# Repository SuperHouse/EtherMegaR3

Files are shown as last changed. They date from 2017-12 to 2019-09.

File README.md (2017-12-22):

EtherMega R3
============
Portions copyright 2011-2013 Freetronics Pty Ltd www.freetronics.com.au  
Portions copyright 2017 SuperHouse Automation Pty Ltd www.superhouse.tv  

The EtherMega R3 is a 100% Arduino-compatible board based on the existing
Mega2560, but with improvements and updates for features and ease of
use. It also includes on-board Ethernet with PoE (Power-over-Ethernet)
support.

Features:

 * High-efficiency switchmode power supply (input voltage 7-28Vdc)
 * Micro-USB Connector
 * microSD card slot
 * 10/100 Ethernet using the Wiznet W5100 chip
 * Overlay guide where you need it (both top and bottom)
 * D13 pin works for everything

You can learn more at:

  https://www.superhouse.tv/ethermega

INSTALLATION
------------
The design is saved as an EAGLE project. EAGLE PCB design software is
available from www.cadsoftusa.com free for non-commercial use. To use
this project download it and place the directory containing these files
into the "eagle" directory on your computer. Then open EAGLE and
navigate to Projects -> eagle -> EtherMegaR3.

DISTRIBUTION
------------
The specific terms of distribution of this project are governed by the
license referenced below.

LICENSE
-------
This work is licensed under the
Creative Commons Attribution-Share Alike License.  
To view a copy of this license, visit

  http://creativecommons.org/licenses/by-sa/3.0/  
  http://creativecommons.org/licenses/by-sa/3.0/legalcode

or send a letter to

  Creative Commons  
  171 Second Street, Suite 300  
  San Francisco  
  California, 94105  
  USA

The "license" folder within this repository also contains copies of the
licences referenced above.

CREDITS
-------
The EtherMega was designed by Marc Alexander (marc@freetronics.com) and
Jonathan Oxer (jon@freetronics.com) based on previous work by the Arduino
team (www.arduino.cc/playground/Main/People) which includes:

 * Massimo Banzi
 * David Cuartielles
 * Tom Igoe
 * Gianluca Martino
 * David A. Mellis

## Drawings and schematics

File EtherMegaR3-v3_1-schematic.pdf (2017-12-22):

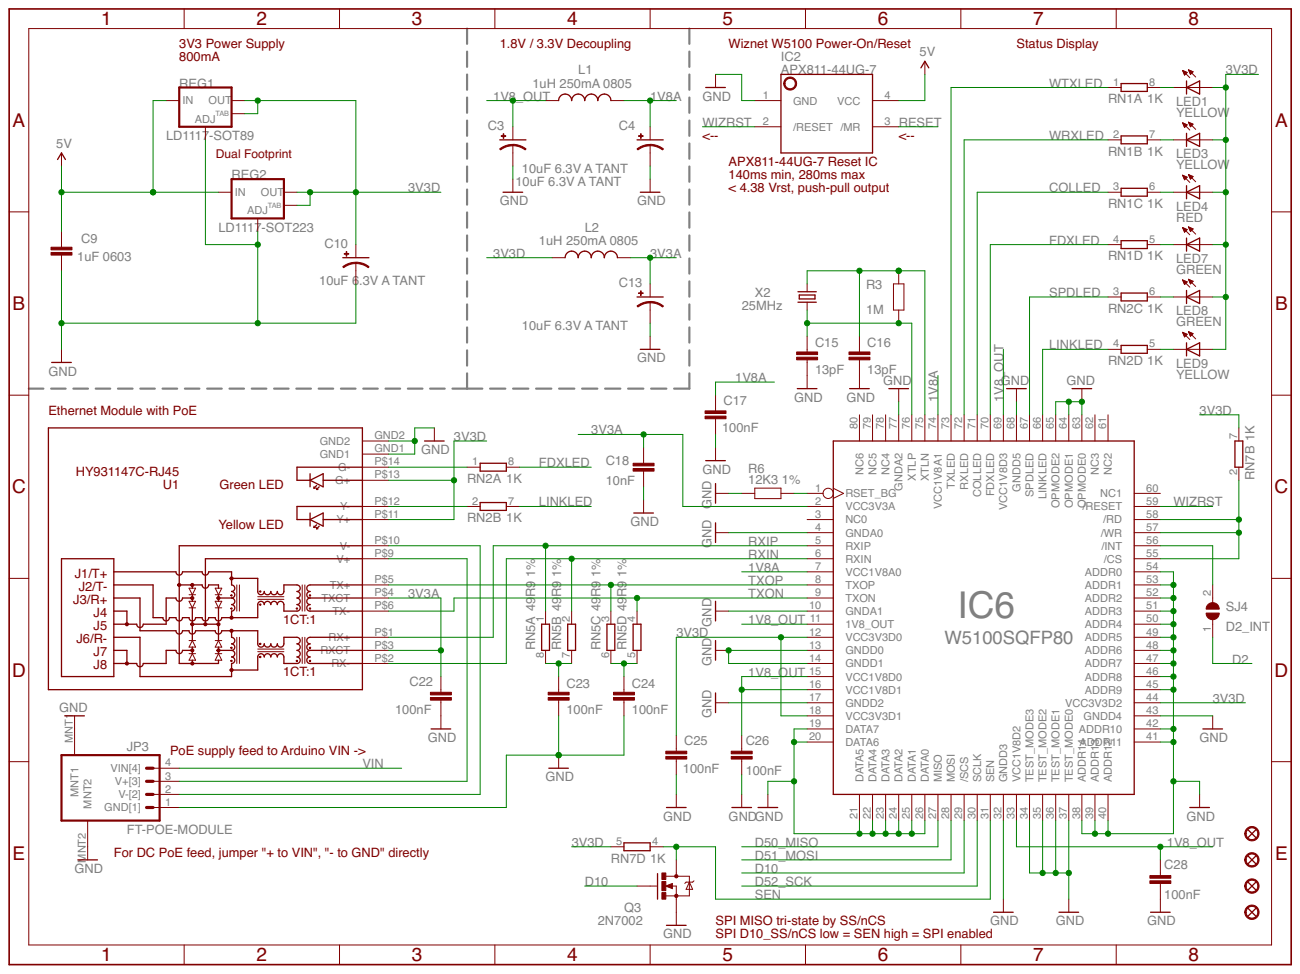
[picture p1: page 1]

Wiznet W5100 Power-On/Reset

Ethernet Module with PoE

GND GND GND GND GND

RXIP | | 56
RXIN | | 55

PoE supply feed to Arduino VIN ->

FT-POE-MODULE
For DC PoE feed, jumper "+ to VIN", "- to GND" directly

SPI MISO tri-state by SS/nCS
SPI D10_SS/nCS low = SEN high = SPI enabled

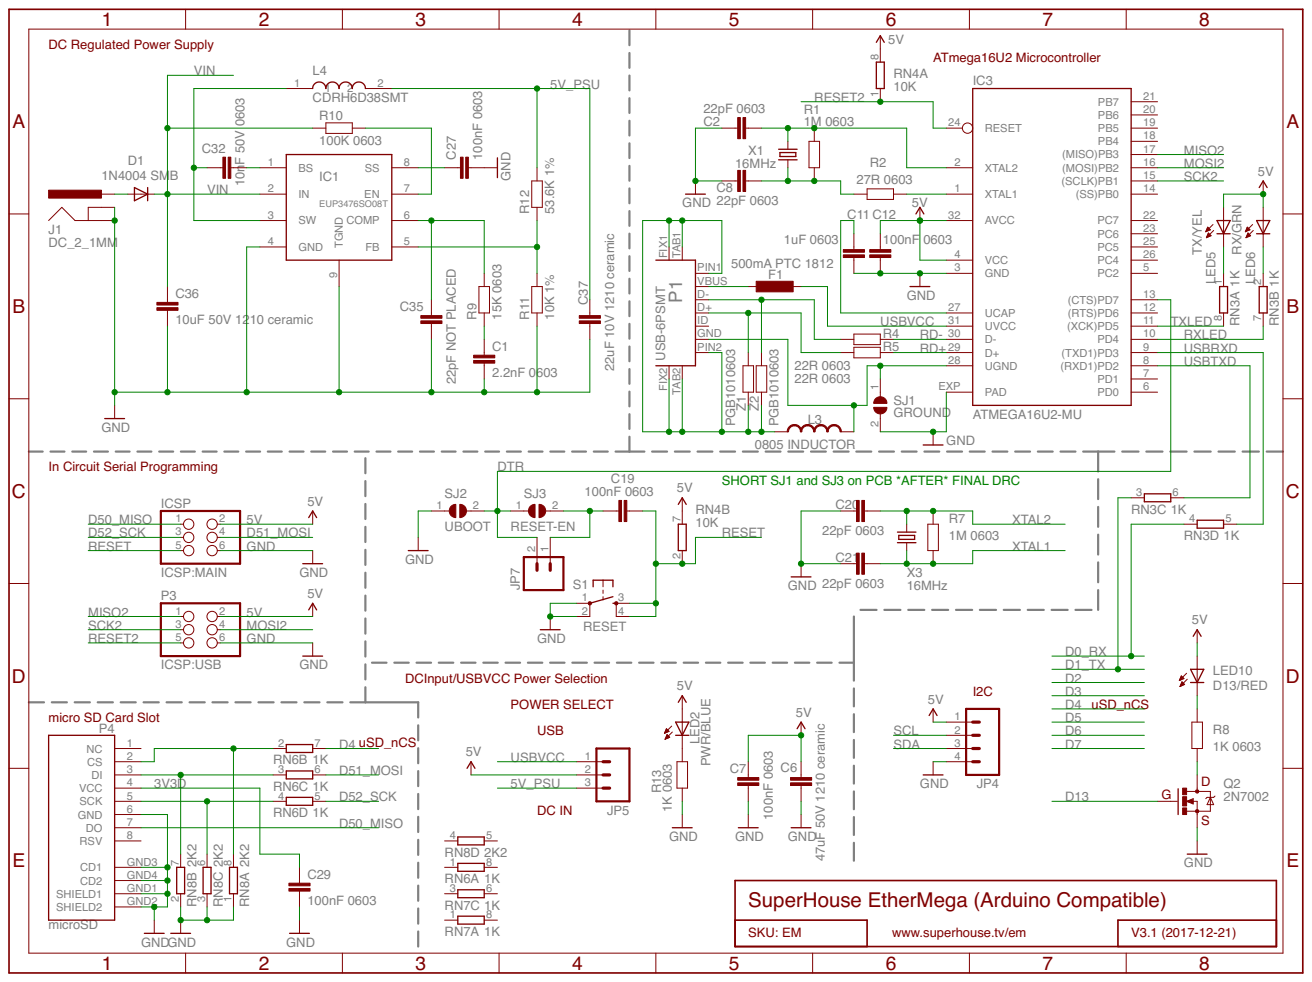
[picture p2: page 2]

DC Regulated Power Supply

10 PD0 8 | USBTXD

R5 | | 9 | USBRXD

EXP

In Circuit Serial Programming

SHORT SJ1 and SJ3 on PCB *AFTER* FINAL DRC

DCInput/USBVCC Power Selection

micro SD Card Slot

4 SCK 3V3D
6 VCC

SuperHouse EtherMega (Arduino Compatible)

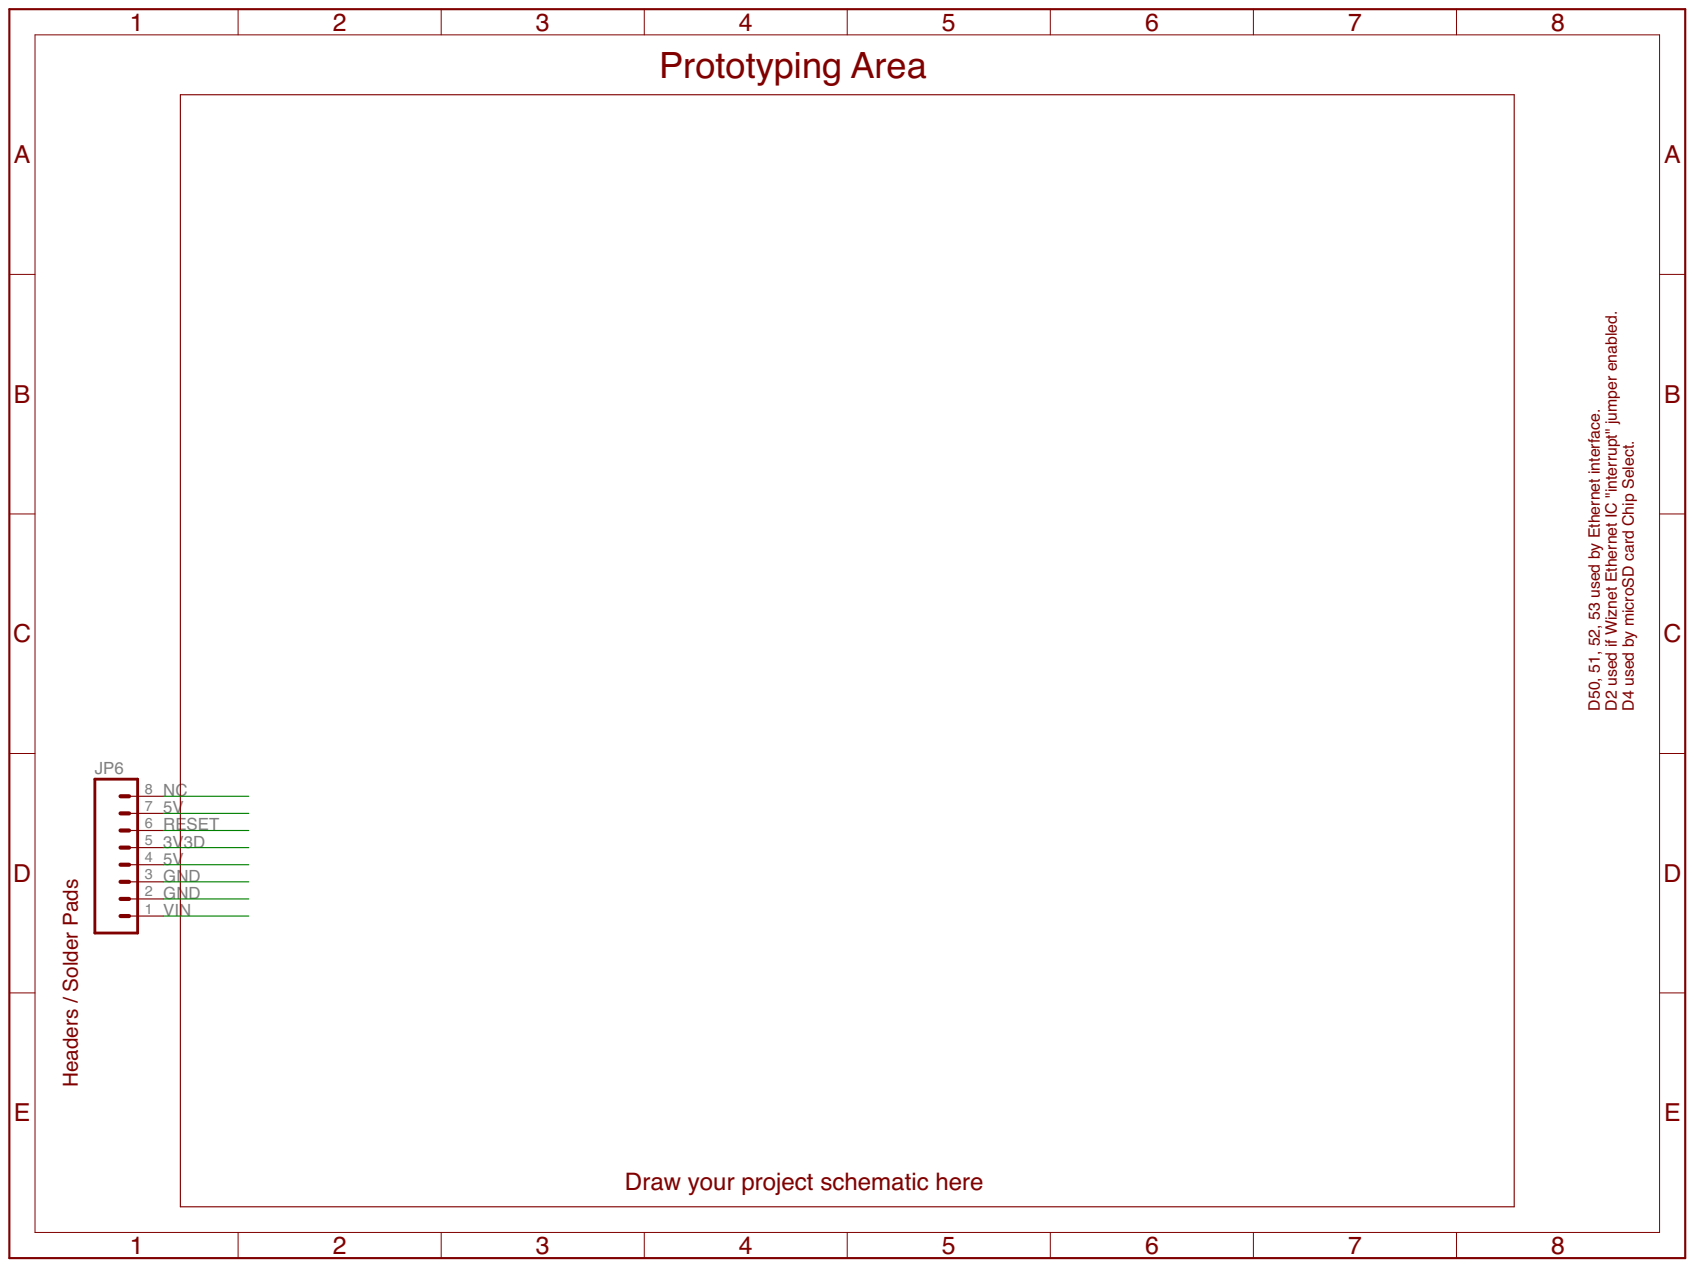
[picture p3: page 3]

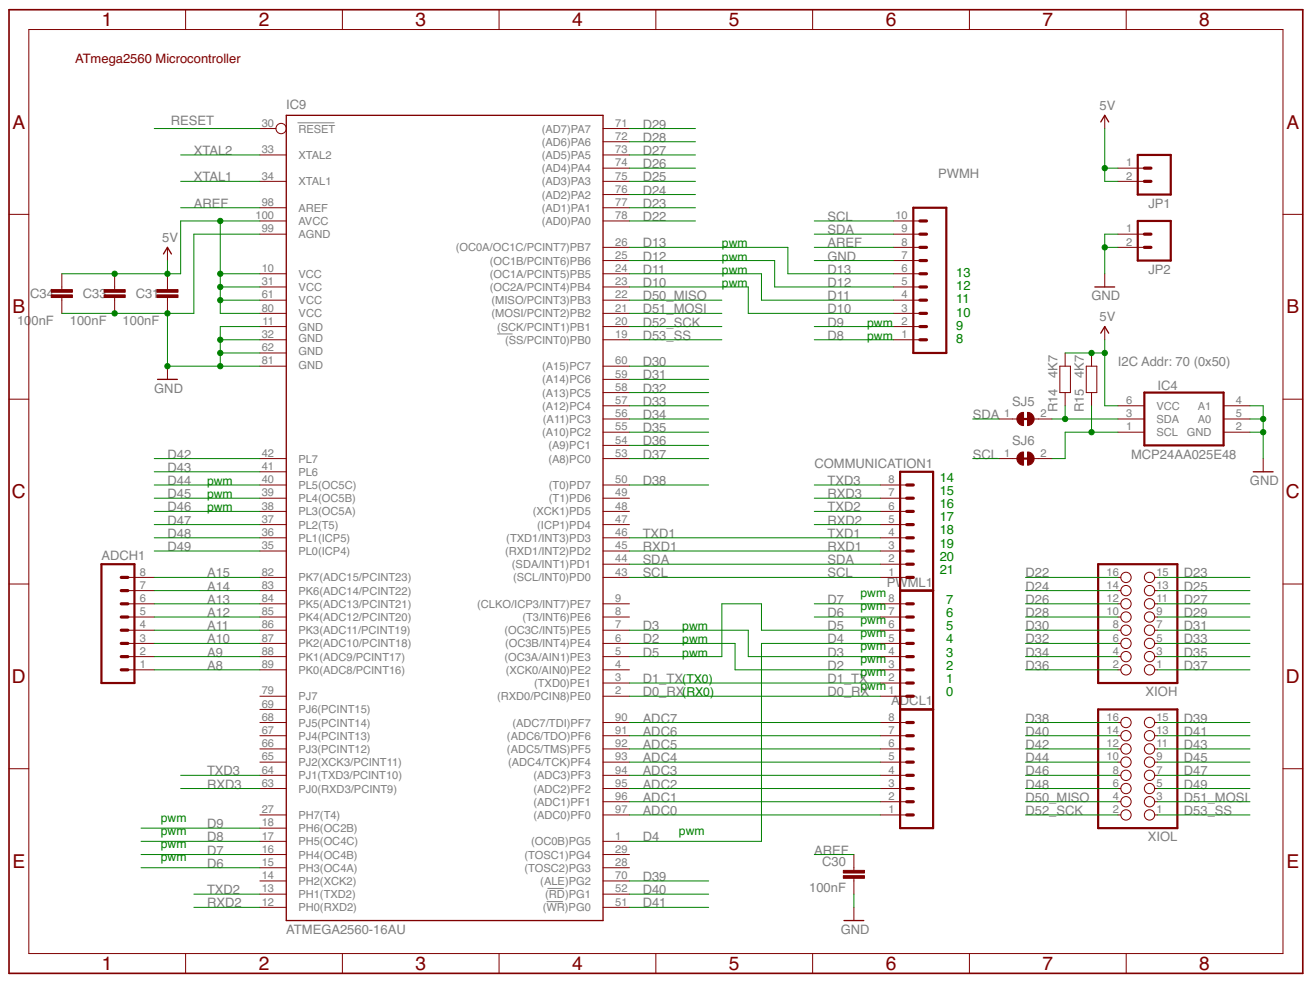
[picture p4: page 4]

D50, 51, 52, 53 used by Ethernet interface. D2 used if Wiznet Ethernet IC "interrupt" jumper enabled.

C31 | | 31 | 23 D10 pwm

61 | | 22 D50_MISO
80 | | 21 D51_MOSI

D4 used by microSD card Chip Select.

6 D2 pwm
5 D5 pwm

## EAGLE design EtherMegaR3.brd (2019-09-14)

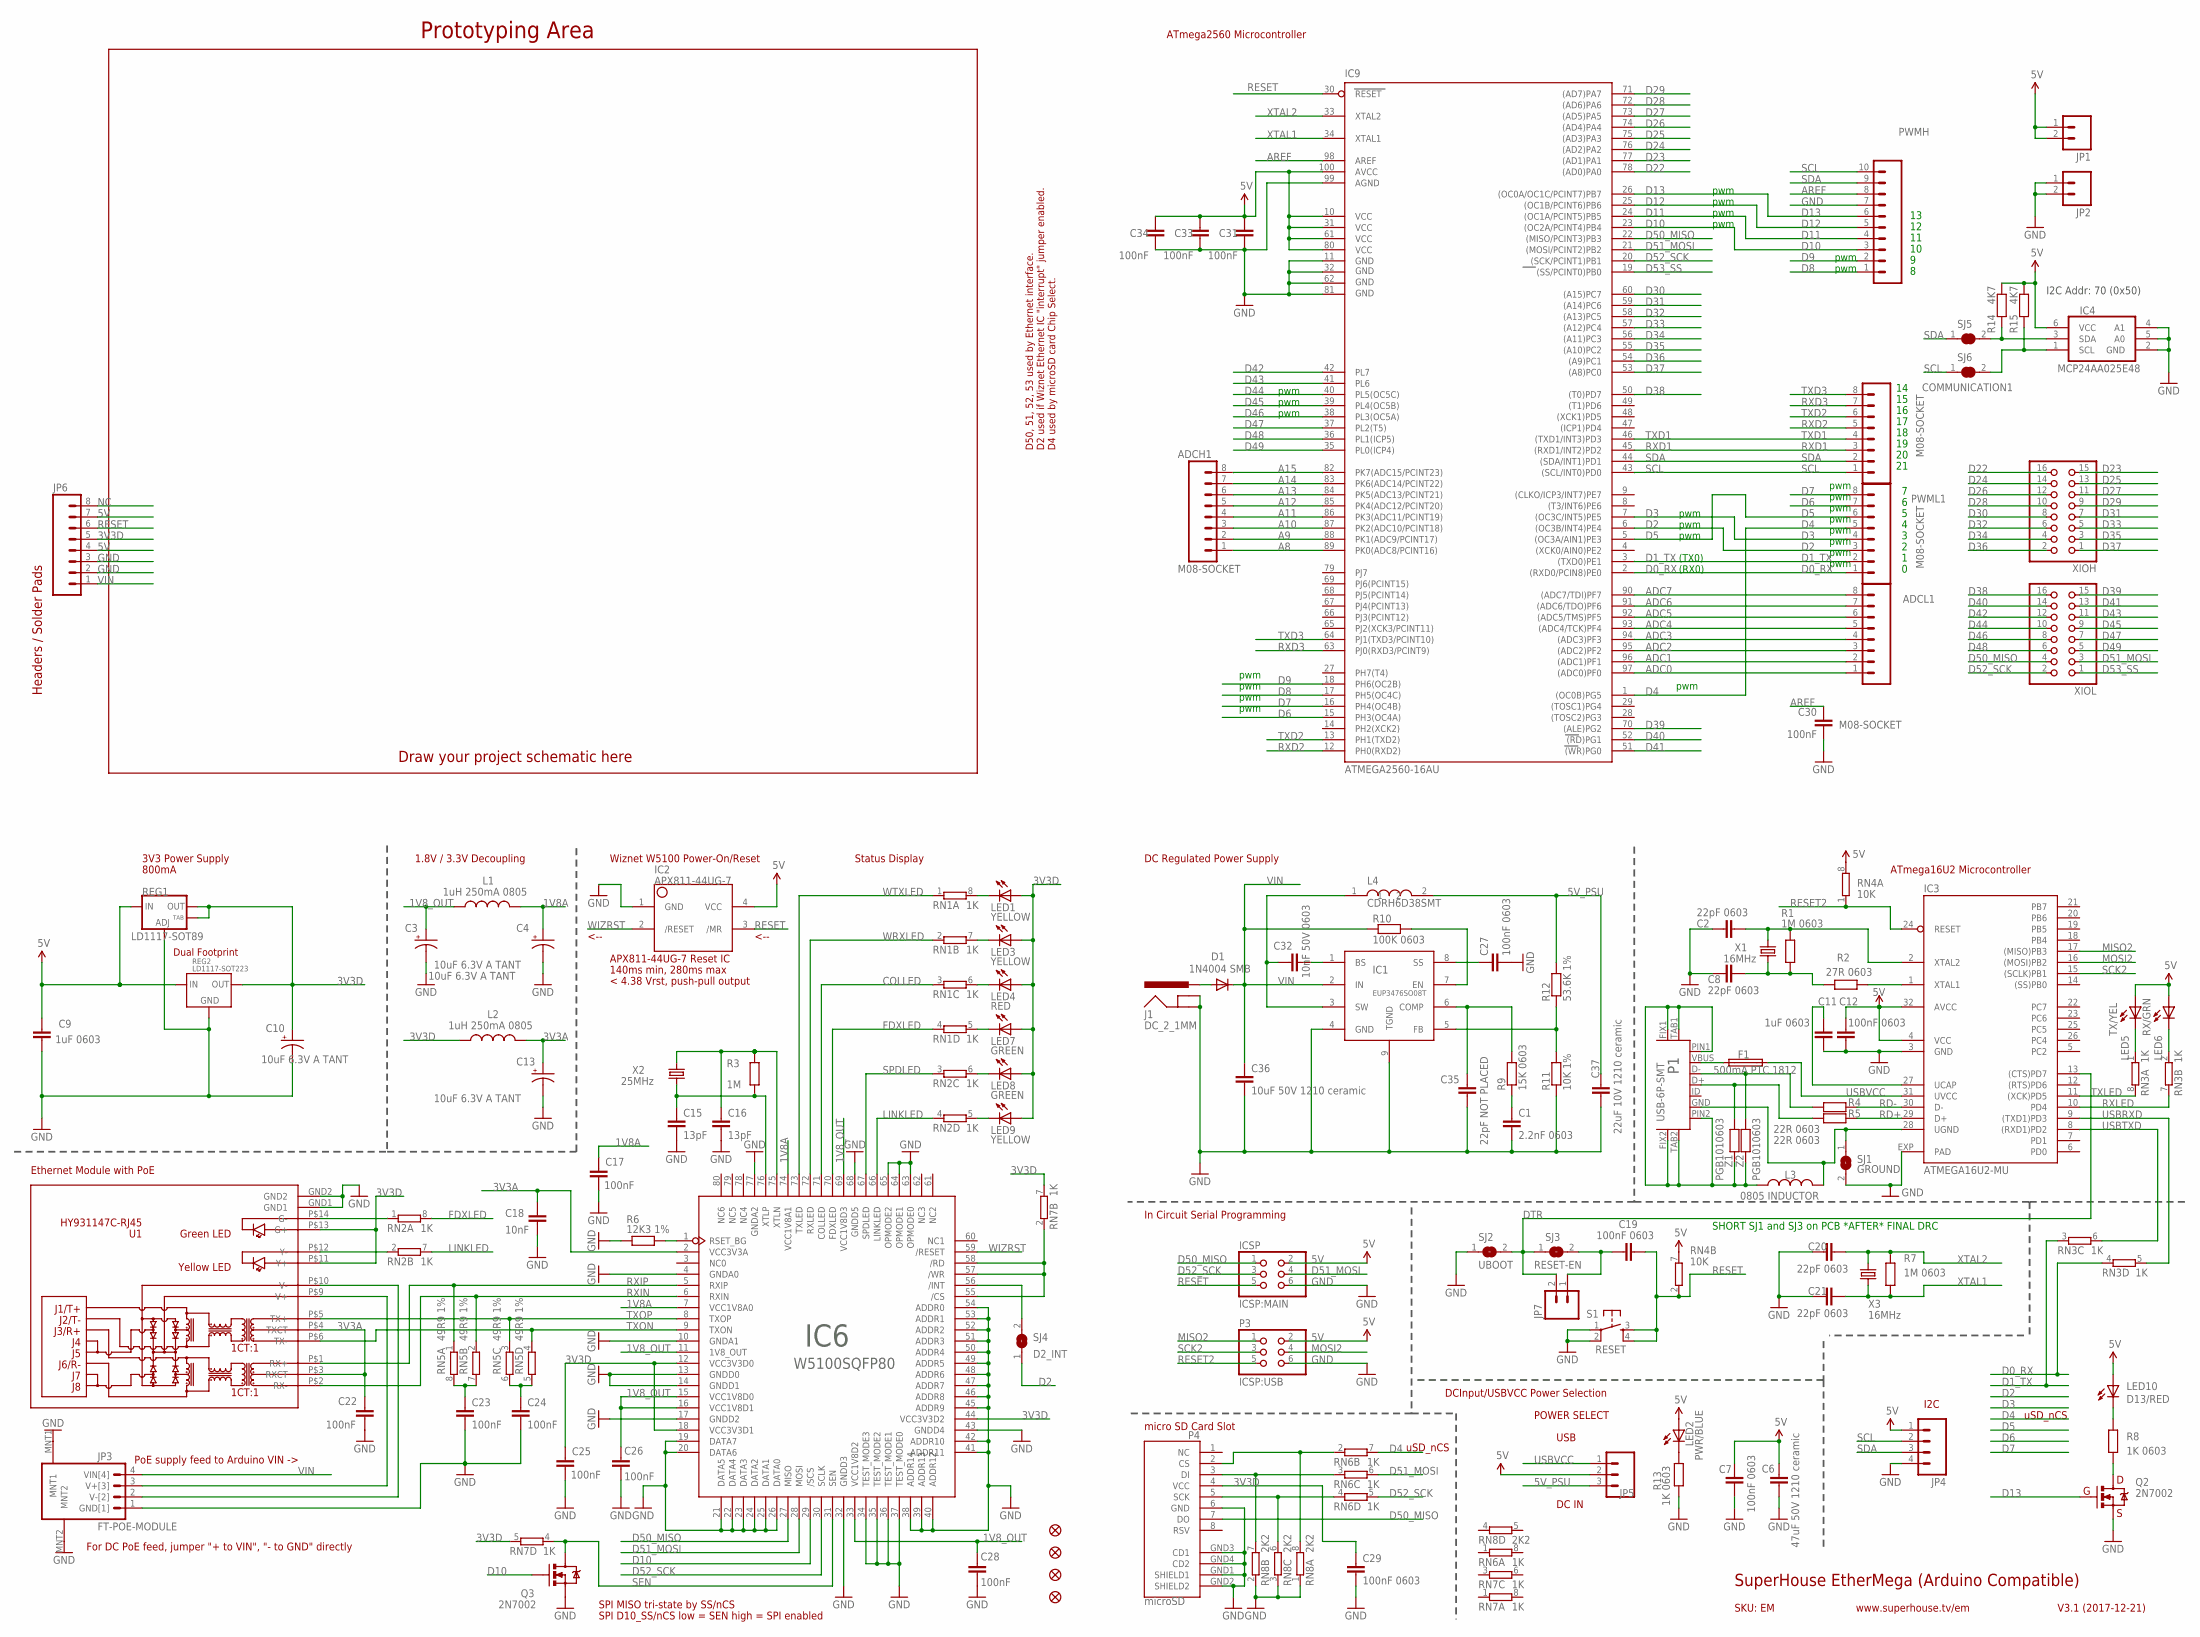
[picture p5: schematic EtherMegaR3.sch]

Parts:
ADCH1: M08-SOCKET; 1X08-S
ADCL1: M08-SOCKET; 1X08-S
C1: 2.2nF 0603; C0603
C2, C8, C20, C21: 22pF 0603; C0603
C3, C4, C10, C13: 10uF 6.3V A TANT; EIA3216
C6: 47uF 50V 1210 ceramic; C1210
C7, C12, C19, C27, C29: 100nF 0603; C0603
C9, C11: 1uF 0603; C0603
C15, C16: 13pF; C0603
C17, C22, C23, C24, C25, C26, C28, C30, C31, C33, C34: 100nF; C0603
C18: 10nF; 0603
C32: 10nF 50V 0603; C0603
C35: 22pF NOT PLACED; C0603
C36: 10uF 50V 1210 ceramic; C1210
C37: 22uF 10V 1210 ceramic; C1210
COMMUNICATION1: M08-SOCKET; 1X08-S
D1: 1N4004 SMB; SMB-DIODE
F1: 500mA PTC 1812; 1812
FID1, FID2, FID3, FID4: FIDUCIAL1X2.5; FIDUCIAL-1X2.5
IC1: EUP3476SO08T; SO08T
IC2: APX811-44UG-7; SOT143-R
IC3: ATMEGA16U2-MU; ATMEL_QFN32
IC4: MCP24AA025E48; SOT23-6
IC6: W5100SQFP80; SQFP80
IC9: ATMEGA2560-16AU; TQFP100
ICSP: ICSP:MAIN; 2X03
J1: DC_2_1MM; POWER_JACK_SLOTS
JP1, JP2, JP7: M02PTH; 1X02
JP3: FT-POE-MODULE; FT-POE-MODULE-CLEAN
JP4: M04PTH; 1X04
JP5: M03-PIN; 1X03-P
JP6: M08STD; 1X08
L1, L2: 1uH 250mA 0805; L2012C
L3: 0805 INDUCTOR; 0805-LARGE
L4: CDRH6D38SMT; CDRH
LED1, LED3, LED9: YELLOW; LED-0603
LED2: PWR/BLUE; LED-0603
LED4: RED; LED-0603
LED5: TX/YEL; LED-0603
LED6: RX/GRN; LED-0603
LED7, LED8: GREEN; LED-0603
LED10: D13/RED; LED-0603
P1: USB-6P-SMT; USB-MICROB-MB05PMXX
P3: ICSP:USB; 2X03
P4: microSD; MOLEX-SD-500901-003
PWMH: M100.1; 1X10
PWML1: M08-SOCKET; 1X08-S
Q2, Q3: 2N7002; SOT23-3
R1, R7: 1M 0603; R0603
R2: 27R 0603; R0603
R3: 1M; R0603
R4, R5: 22R 0603; R0603
R6: 12K3 1%; R0603
R8, R13: 1K 0603; R0603
R9: 15K 0603; R0603
R10: 100K 0603; R0603
R11: 10K 1%; R0603
R12: 53.6K 1%; 0603
R14, R15: 4K7; R0603
REG1: LD1117-SOT89; SOT89
REG2: LD1117-SOT223; SOT-223
RN1, RN2, RN3, RN6, RN7: 1K; CAY16
RN4: 10K; CAY16
RN5: 49R9 1%; CAY16
RN8: 2K2; CAY16
S1: RESET; TACTILE_SMD-6MM
SJ1: GROUND; SJ
SJ2: UBOOT; SJ
SJ3: RESET-EN; SJ
SJ4: D2_INT; SJ
SJ5, SJ6: SJCN; SJC
U1: HY931147C-RJ45; HY931147C
X1, X3: 16MHz; HC49U-V
X2: 25MHz; HC49U-V
XIOH: PINHD-2X8; 2X08
XIOL: PINHD-2X8; 2X08
Z1, Z2: PGB1010603; 0603

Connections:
1V8A: C4.A (+), C17.1, IC6.7 (VCC1V8A0), IC6.74 (VCC1V8A1), L1.2
1V8_OUT: C3.A (+), C26.1, C28.1, IC6.11 (1V8_OUT), IC6.15 (VCC1V8D0), IC6.16 (VCC1V8D1), IC6.33 (VCC1V8D2), IC6.69 (VCC1V8D3), L1.1
3V3A: C13.A (+), C18.1, C22.1, IC6.2 (VCC3V3A), L2.2, U1.P$3 (RXCT), U1.P$4 (TXCT)
3V3D: C10.A (+), C25.1, C29.1, IC6.12 (VCC3V3D0), IC6.18 (VCC3V3D1), IC6.44 (VCC3V3D2), JP6.5, L2.1, LED1.A, LED3.A, LED4.A, LED7.A, LED8.A, LED9.A, P4.4 (VCC), REG1.2 (OUT), REG1.4 (OUT), REG2.2 (OUT), REG2.4 (OUT), RN7.5 (2), RN7.7 (2), U1.P$11 (Y+), U1.P$13 (G+)
5V: C6.2, C7.1, C9.1, C12.1, C31.1, C33.1, C34.1, IC2.4 (VCC), IC3.4 (VCC), IC3.32 (AVCC), IC4.6 (VCC), IC9.10 (VCC), IC9.31 (VCC1), IC9.61 (VCC2), IC9.80 (VCC3), IC9.100 (AVCC), ICSP.2, JP1.1, JP1.2, JP4.1, JP5.2, JP6.4, JP6.7, LED2.A, LED5.A, LED6.A, LED10.A, P3.2, R14.1, R15.1, REG1.3 (IN), REG2.3 (IN), RN4.7 (2), RN4.8 (2)
5V_PSU: C37.1, JP5.3, L4.2, R12.2
A8: ADCH1.1, IC9.89 (PK0(ADC8/PCINT16))
A9: ADCH1.2, IC9.88 (PK1(ADC9/PCINT17))
A10: ADCH1.3, IC9.87 (PK2(ADC10/PCINT18))
A11: ADCH1.4, IC9.86 (PK3(ADC11/PCINT19))
A12: ADCH1.5, IC9.85 (PK4(ADC12/PCINT20))
A13: ADCH1.6, IC9.84 (PK5(ADC13/PCINT21))
A14: ADCH1.7, IC9.83 (PK6(ADC14/PCINT22))
A15: ADCH1.8, IC9.82 (PK7(ADC15/PCINT23))
ADC0: ADCL1.1, IC9.97 ((ADC0)PF0)
ADC1: ADCL1.2, IC9.96 ((ADC1)PF1)
ADC2: ADCL1.3, IC9.95 ((ADC2)PF2)
ADC3: ADCL1.4, IC9.94 ((ADC3)PF3)
ADC4: ADCL1.5, IC9.93 ((ADC4/TCK)PF4)
ADC5: ADCL1.6, IC9.92 ((ADC5/TMS)PF5)
ADC6: ADCL1.7, IC9.91 ((ADC6/TDO)PF6)
ADC7: ADCL1.8, IC9.90 ((ADC7/TDI)PF7)
AREF: C30.1, IC9.98 (AREF), PWMH.8
COLLED: IC6.71 (COLLED), RN1.3 (1)
D0_RX: IC9.2 ((RXD0/PCIN8)PE0), PWML1.1, RN3.4 (1)
D1_TX: IC9.3 ((TXD0)PE1), PWML1.2, RN3.3 (1)
D2: IC9.6 ((OC3B/INT4)PE4), PWML1.3, SJ4.1
D3: IC9.7 ((OC3C/INT5)PE5), PWML1.4
D4: IC9.1 ((OC0B)PG5), PWML1.5, RN6.7 (2)
D5: IC9.5 ((OC3A/AIN1)PE3), PWML1.6
D6: IC9.15 (PH3(OC4A)), PWML1.7
D7: IC9.16 (PH4(OC4B)), PWML1.8
D8: IC9.17 (PH5(OC4C)), PWMH.1
D9: IC9.18 (PH6(OC2B)), PWMH.2
D10: IC6.29 (/SCS), IC9.23 ((OC2A/PCINT4)PB4), PWMH.3, Q3.1 (G)
D11: IC9.24 ((OC1A/PCINT5)PB5), PWMH.4
D12: IC9.25 ((OC1B/PCINT6)PB6), PWMH.5
D13: IC9.26 ((OC0A/OC1C/PCINT7)PB7), PWMH.6, Q2.1 (G)
D22: IC9.78 ((AD0)PA0), XIOH.16
D23: IC9.77 ((AD1)PA1), XIOH.15
D24: IC9.76 ((AD2)PA2), XIOH.14
D25: IC9.75 ((AD3)PA3), XIOH.13
D26: IC9.74 ((AD4)PA4), XIOH.12
D27: IC9.73 ((AD5)PA5), XIOH.11
D28: IC9.72 ((AD6)PA6), XIOH.10
D29: IC9.71 ((AD7)PA7), XIOH.9
D30: IC9.60 ((A15)PC7), XIOH.8
D31: IC9.59 ((A14)PC6), XIOH.7
D32: IC9.58 ((A13)PC5), XIOH.6
D33: IC9.57 ((A12)PC4), XIOH.5
D34: IC9.56 ((A11)PC3), XIOH.4
D35: IC9.55 ((A10)PC2), XIOH.3
D36: IC9.54 ((A9)PC1), XIOH.2
D37: IC9.53 ((A8)PC0), XIOH.1
D38: IC9.50 ((T0)PD7), XIOL.16
D39: IC9.70 ((ALE)PG2), XIOL.15
D40: IC9.52 ((RD)PG1), XIOL.14
D41: IC9.51 ((WR)PG0), XIOL.13
D42: IC9.42 (PL7), XIOL.12
D43: IC9.41 (PL6), XIOL.11
D44: IC9.40 (PL5(OC5C)), XIOL.10
D45: IC9.39 (PL4(OC5B)), XIOL.9
D46: IC9.38 (PL3(OC5A)), XIOL.8
D47: IC9.37 (PL2(T5)), XIOL.7
D48: IC9.36 (PL1(ICP5)), XIOL.6
D49: IC9.35 (PL0(ICP4)), XIOL.5
D50_MISO: IC6.27 (MISO), IC9.22 ((MISO/PCINT3)PB3), ICSP.1, P4.7 (DO), XIOL.4
D51_MOSI: IC6.28 (MOSI), IC9.21 ((MOSI/PCINT2)PB2), ICSP.4, RN6.6 (2), XIOL.3
D52_SCK: IC6.30 (SCLK), IC9.20 ((SCK/PCINT1)PB1), ICSP.3, RN6.5 (2), XIOL.2
D53_SS: IC9.19 ((SS/PCINT0)PB0), XIOL.1
DTR: IC3.13 ((CTS)PD7), JP7.2, SJ2.2, SJ3.1
FDXLED: IC6.70 (FDXLED), RN1.4 (1), RN2.8 (2)
GND: C1.2, C2.1, C3.C (-), C4.C (-), C6.1, C7.2, C8.1, C9.2, C10.C (-), C11.2, C12.2, C13.C (-), C15.2, C16.2, C17.2, C18.2, C20.1, C21.1, C22.2, C23.2, C24.2, C25.2, C26.2, C27.2, C28.2, C29.2, C30.2, C31.2, C33.2, C34.2, C35.2, C36.2, C37.2, IC1.4 (GND), IC1.9 (TGND), IC2.1 (GND), IC3.3 (GND), IC3.EXP (PAD), IC4.2 (GND), IC4.4 (A1), IC4.5 (A0), IC6.4 (GNDA0), IC6.10 (GNDA1), IC6.13 (GNDD0), IC6.14 (GNDD1), IC6.17 (GNDD2), IC6.19 (DATA7), IC6.20 (DATA6), IC6.21 (DATA5), IC6.22 (DATA4), IC6.23 (DATA3), IC6.24 (DATA2), IC6.25 (DATA1), IC6.26 (DATA0), IC6.32 (GNDD3), IC6.34 (TEST_MODE3), IC6.35 (TEST_MODE2), IC6.36 (TEST_MODE1), IC6.37 (TEST_MODE0), IC6.38 (ADDR14), IC6.39 (ADDR13), IC6.40 (ADDR12), IC6.41 (ADDR11), IC6.42 (ADDR10), IC6.43 (GNDD4), IC6.45 (ADDR9), IC6.46 (ADDR8), IC6.47 (ADDR7), IC6.48 (ADDR6), IC6.49 (ADDR5), IC6.50 (ADDR4), IC6.51 (ADDR3), IC6.52 (ADDR2), IC6.53 (ADDR1), IC6.54 (ADDR0), IC6.63 (OPMODE0), IC6.64 (OPMODE1), IC6.65 (OPMODE2), IC6.68 (GNDD5), IC6.77 (GNDA2), IC9.11 (GND), IC9.32 (GND1), IC9.62 (GND2), IC9.81 (GND3), IC9.99 (AGND), ICSP.6, J1.GND, J1.GNDBREAK, JP2.1, JP2.2, JP3.1 (GND[1]), JP3.MNT1, JP3.MNT2, JP4.4, JP6.2, JP6.3, P3.6, P4.6 (GND), P4.GND1 (SHIELD1), P4.GND2 (SHIELD2), P4.GND3 (CD1), P4.GND4 (CD2), PWMH.7, Q2.2 (S), Q3.2 (S), R6.1, R11.1, R13.1, REG1.1 (ADJ), REG2.1 (GND), RN8.1, RN8.2 (1), RN8.3 (1), S1.1, S1.2, SJ1.2, SJ2.1, U1.GND1, U1.GND2
LINKLED: IC6.66 (LINKLED), RN2.4 (1), RN2.7 (2)
MISO2: IC3.17 ((MISO)PB3), P3.1
MOSI2: IC3.16 ((MOSI)PB2), P3.4
unnamed: C24.1, RN5.5 (2), RN5.6 (2)
unnamed: LED10.C, R8.2
unnamed: Q2.3 (D), R8.1
unnamed: IC3.1 (XTAL1), R2.1
unnamed: IC4.1 (SCL), R15.2, SJ6.2
unnamed: LED6.C, RN3.2 (1)
unnamed: LED2.C, R13.2
unnamed: LED5.C, RN3.1
unnamed: P1.D+, R5.2, Z1.1
unnamed: P1.D-, R4.2, Z2.1
unnamed: L3.1, P1.FIX1, P1.FIX2, P1.PIN1, P1.PIN2, P1.TAB1, P1.TAB2, Z1.2, Z2.2
unnamed: IC4.3 (SDA), R14.2, SJ5.2
unnamed: P4.5 (SCK), RN6.4 (1), RN8.6 (2)
unnamed: P4.2 (CS), RN6.2 (1), RN8.8 (2)
unnamed: P4.3 (DI), RN6.3 (1), RN8.7 (2)
unnamed: LED8.C, RN2.6 (2)
unnamed: IC6.55 (/CS), IC6.57 (/WR), IC6.58 (/RD), RN7.2 (1)
unnamed: LED9.C, RN2.5 (2)
unnamed: D1.A, J1.PWR
unnamed: IC6.56 (/INT), SJ4.2
unnamed: C27.1, IC1.8 (SS)
unnamed: C1.1, R9.1
unnamed: C35.1, IC1.6 (COMP), R9.2
unnamed: RN2.1, U1.P$14 (G-)
unnamed: JP3.3 (V+[3]), U1.P$9 (V+)
unnamed: JP3.2 (V-[2]), U1.P$10 (V-)
unnamed: C32.1, IC1.3 (SW), L4.1
unnamed: C32.2, IC1.1 (BS)
unnamed: IC1.7 (EN), R10.2
unnamed: IC3.28 (UGND), L3.2, P1.GND, SJ1.1
unnamed: C19.1, JP7.1, SJ3.2
unnamed: IC1.5 (FB), R11.2, R12.1
unnamed: C2.2, IC3.2 (XTAL2), R1.2, X1.2
unnamed: C8.2, R1.1, R2.2, X1.1
unnamed: F1.1, P1.VBUS
unnamed: C11.1, IC3.27 (UCAP)
unnamed: C23.1, RN5.7 (2), RN5.8 (2)
unnamed: IC6.1 (RSET_BG), R6.2
unnamed: LED7.C, RN1.5 (2)
unnamed: LED4.C, RN1.6 (2)
unnamed: LED3.C, RN1.7 (2)
unnamed: LED1.C, RN1.8 (2)
unnamed: RN2.2 (1), U1.P$12 (Y-)
NC: JP6.8
RD+: IC3.29 (D+), R5.1
RD-: IC3.30 (D-), R4.1
RESET: C19.2, IC2.3 (/MR), IC9.30 (RESET), ICSP.5, JP6.6, RN4.2 (1), S1.3, S1.4
RESET2: IC3.24 (RESET), P3.5, RN4.1
RXD1: COMMUNICATION1.3, IC9.45 ((RXD1/INT2)PD2)
RXD2: COMMUNICATION1.5, IC9.12 (PH0(RXD2))
RXD3: COMMUNICATION1.7, IC9.63 (PJ0(RXD3/PCINT9))
RXIN: IC6.6 (RXIN), RN5.2 (1), U1.P$2 (RX-)
RXIP: IC6.5 (RXIP), RN5.1, U1.P$1 (RX+)
RXLED: IC3.10 (PD4), RN3.7 (2)
SCK2: IC3.15 ((SCLK)PB1), P3.3
SCL: COMMUNICATION1.1, IC9.43 ((SCL/INT0)PD0), JP4.2, PWMH.10, SJ6.1
SDA: COMMUNICATION1.2, IC9.44 ((SDA/INT1)PD1), JP4.3, PWMH.9, SJ5.1
SEN: IC6.31 (SEN), Q3.3 (D), RN7.4 (1)
SPDLED: IC6.67 (SPDLED), RN2.3 (1)
TXD1: COMMUNICATION1.4, IC9.46 ((TXD1/INT3)PD3)
TXD2: COMMUNICATION1.6, IC9.13 (PH1(TXD2))
TXD3: COMMUNICATION1.8, IC9.64 (PJ1(TXD3/PCINT10))
TXLED: IC3.11 ((XCK)PD5), RN3.8 (2)
TXON: IC6.9 (TXON), RN5.4 (1), U1.P$6 (TX-)
TXOP: IC6.8 (TXOP), RN5.3 (1), U1.P$5 (TX+)
USBRXD: IC3.9 ((TXD1)PD3), RN3.5 (2)
USBTXD: IC3.8 ((RXD1)PD2), RN3.6 (2)
USBVCC: F1.2, IC3.31 (UVCC), JP5.1
VIN: C36.1, D1.C, IC1.2 (IN), JP3.4 (VIN[4]), JP6.1, R10.1
WIZRST: IC2.2 (/RESET), IC6.59 (/RESET)
WRXLED: IC6.72 (RXLED), RN1.2 (1)
WTXLED: IC6.73 (TXLED), RN1.1
XTAL1: C21.2, IC9.34 (XTAL1), R7.1, X3.1
XTAL2: C20.2, IC9.33 (XTAL2), R7.2, X3.2
XTLN: C16.1, IC6.75 (XTLN), R3.2, X2.2
XTLP: C15.1, IC6.76 (XTLP), R3.1, X2.1

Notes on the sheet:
Prototyping Area
3V3 Power Supply
Status Display
Headers / Solder Pads
Dual Footprint
1.8V / 3.3V Decoupling
Draw your project schematic here
D50, 51, 52, 53 used by Ethernet interface.
D2 used if Wiznet Ethernet IC "interrupt" jumper enabled.
PoE supply feed to Arduino VIN ->
SPI MISO tri-state by SS/nCS
SPI D10_SS/nCS low = SEN high = SPI enabled
For DC PoE feed, jumper "+ to VIN", "- to GND" directly
DC Regulated Power Supply
ATmega2560 Microcontroller
APX811-44UG-7 Reset IC
140ms min, 280ms max
ATmega16U2 Microcontroller
DCInput/USBVCC Power Selection
Wiznet W5100 Power-On/Reset
uSD_nCS
800mA
In Circuit Serial Programming
micro SD Card Slot
SuperHouse EtherMega (Arduino Compatible)
V3.1 (2017-12-21)
www.superhouse.tv/em
SKU: EM
Ethernet Module with PoE
< 4.38 Vrst, push-pull output
<--
D4 used by microSD card Chip Select.
pwm
(TX0)
(RX0)
SHORT SJ1 and SJ3 on PCB *AFTER* FINAL DRC
I2C
USB
DC IN
POWER SELECT

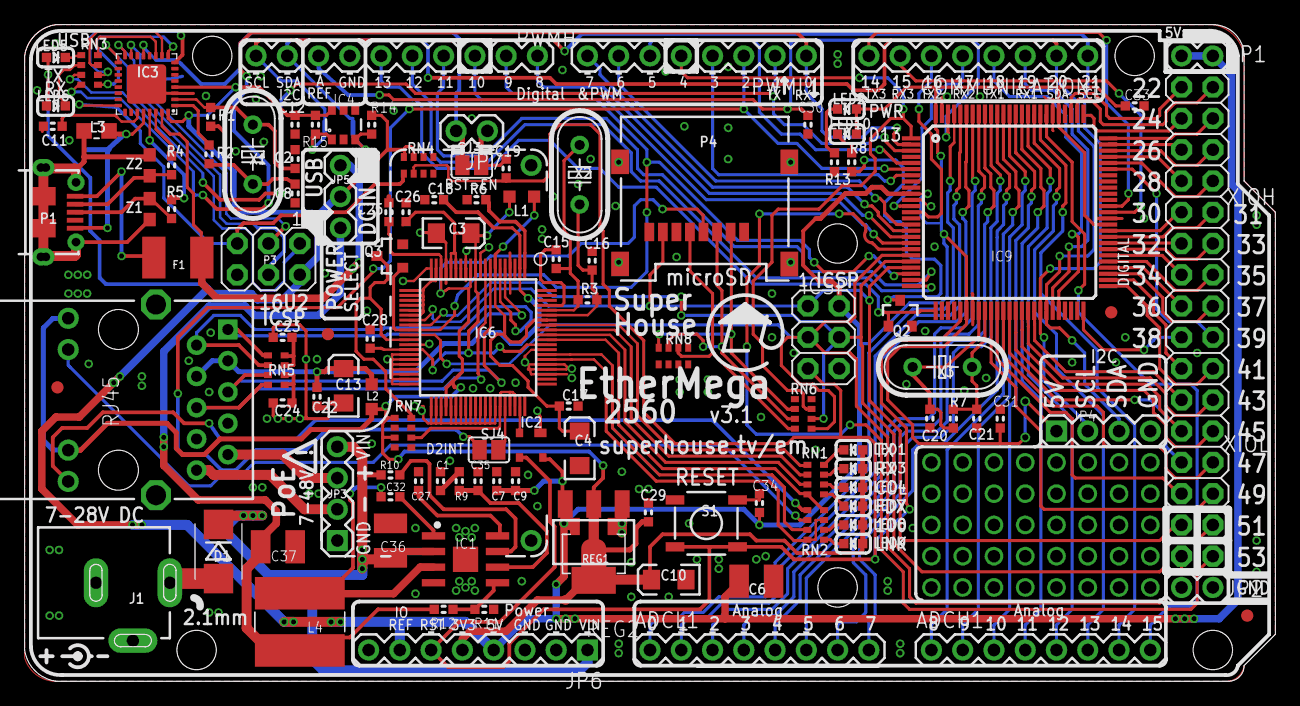
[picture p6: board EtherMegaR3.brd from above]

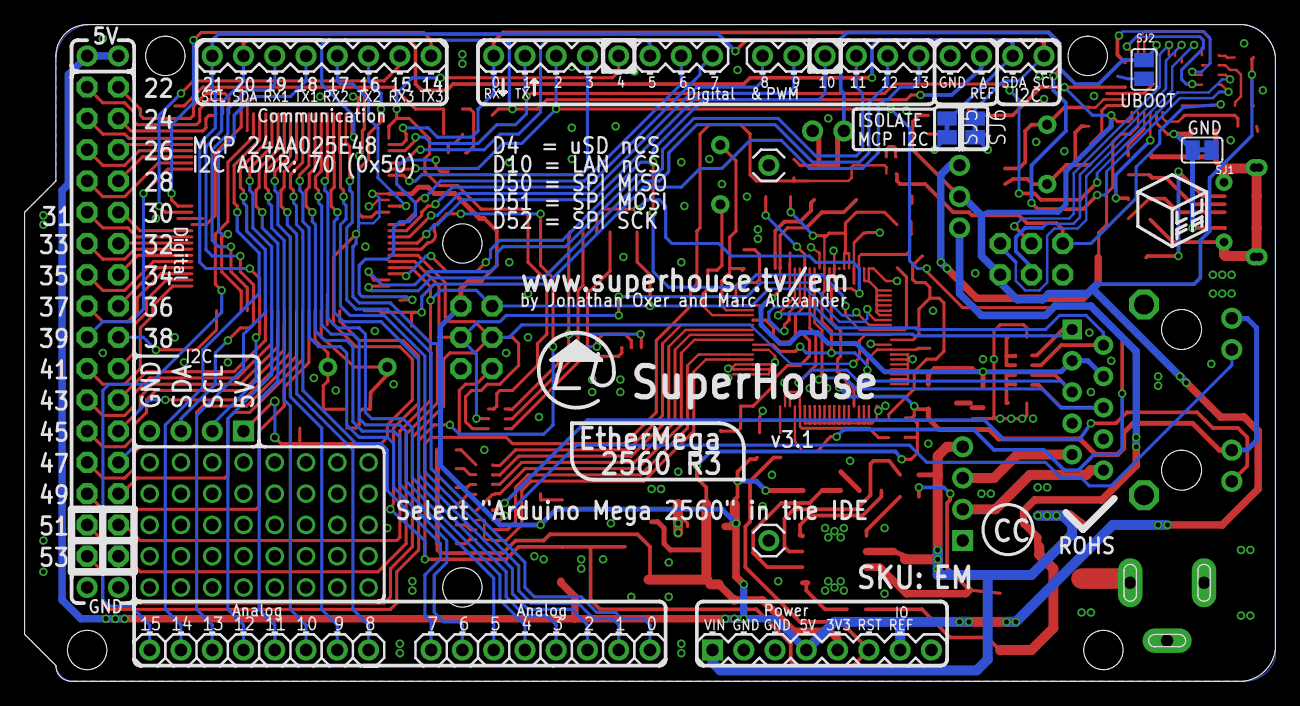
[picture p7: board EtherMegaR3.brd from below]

Board: 2 copper layers, 101.6 x 53.3 mm, 120 parts (4 on the bottom side), 151 nets.

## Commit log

2017-12-22 Changed branding to SuperHouse for v3.1 release
    [EtherMegaR3.brd, EtherMegaR3.sch]
2017-12-22 Updated schematic and readme
2019-09-14 Part replacement using SuperHouse libraries
    [EtherMegaR3.brd, EtherMegaR3.sch]
